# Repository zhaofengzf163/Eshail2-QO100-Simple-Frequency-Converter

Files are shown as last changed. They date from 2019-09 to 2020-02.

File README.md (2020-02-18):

# Eshail2-QO100-Simple-Frequency-Converter
   Eshail2 QO100 简易频率转换器

## 背景资料：
BG0AUB 中国HAM，QTH:NN33   .从2019年2月开始对QO100同步卫星转发器产生兴趣，经过一些准备，在2月24日在QO100与PA3FYM完成了第一个QSO.当时使用的设备为limesdr mini+移动通讯基站改装的2.4G功放。经过半年的摸索,尝试设计制作了这个工作在QO100的上行频率转换器（集成LNB基准产生，自动检测PTT控制。只需一根馈线连接到频率变换器即可工作）实现一根馈线直连电台输出直连馈源LNB即可工作。
最初的思路来源于PE1CKK的一张框图
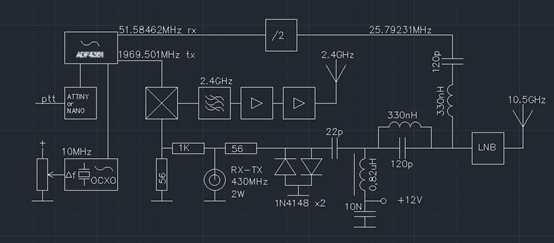
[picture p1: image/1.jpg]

整体思路很简洁。ADF4351在接收状态产生51.58462Mhz信号经过2分频后得到25.79231Mhz基准信号通过双工器送到LNB内部的PLL基准输入。（例如：没有经过修改的LNB本振为9750Mhz，QO100 cw信标10489.550，如果没有任何改动那么IF=10489.550-9750=739.550，为了把IF调整到430Mhz，方便电台直接接收，需要把LNB本振调整到10489.550-430.550=10050Mhz。LNB内部使用25M晶振作为PLL基准，调整这个基准频率就可以调整PLL输出。于是就有了25.7923）这样LNB会输出稳定的430M中频信号，方便全模式电台直接接收。
    发射部分：ADF4351在发射状态产生1969.500Mhz。电台发射信号430.550Mhz，经过混频器上变频后得到1969.5+430.550=2400.05Mhz。经过滤波放大后送到馈源发射上行到卫星。

## 技术方案：
1：频率转换器:  adf4351为核心的PLL。通过ATTINY13控制，产生的RX本振经过SPF5189放到后送入74ac74二分频，经过滤波后送入LNB.当检测到PTT时，产生的TX本振经过SPF5189放大后（10DB）送入HMC213混频器，同时电台送入的430M信号经过衰减器后(13DB)送入混频器，得到2.4G的输出到SF2124滤波后经过一级SPF5189放大后，再次经过SF2124滤波后输出。最终获得约4-5db的纯净输出。(PCB集成了ATTINY13，作为RX/TX收发频率转换控制，PTT信号通过检测430Mhz信号自动获取方便使用)
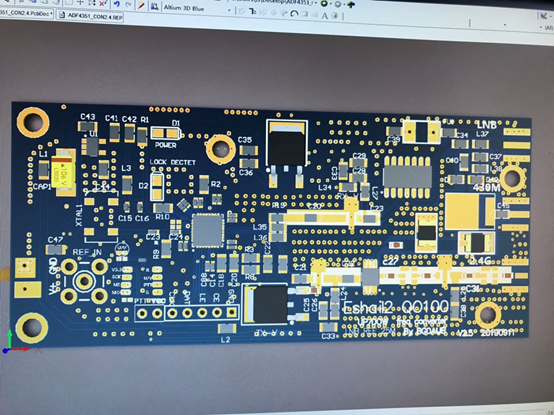
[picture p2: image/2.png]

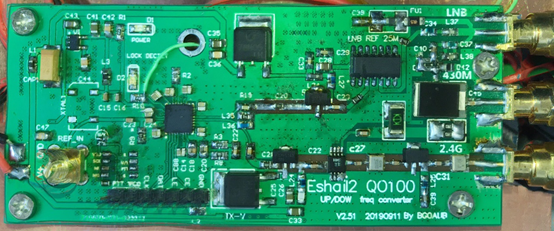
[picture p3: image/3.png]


2: S波段前置放大器（-5DB输入30DB输出）三级组成。输入信号经过滤波器后进入E5放大后再次滤波然后经过AH1驱动FLL357最终输出30-32DB.P1DB=30   PCB使用的廉价的FR4 0.8mm板材。
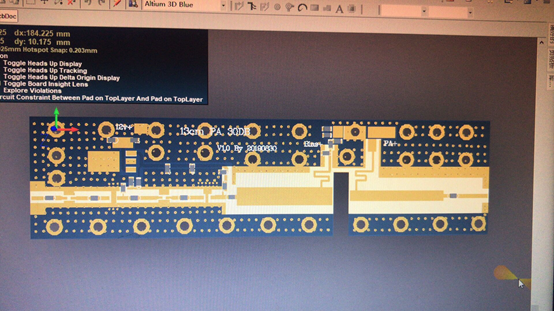
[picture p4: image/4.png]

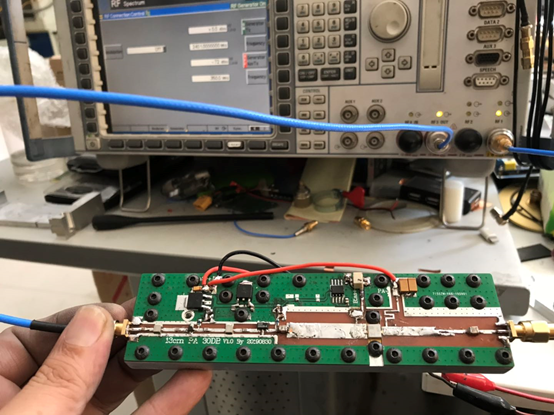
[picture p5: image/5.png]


3：S波段末级放大器 （40+DB输出）。MRF21045,仍然时廉价的FR4 0.8mm板材，实际测试在30db输入时可以得到40-42db输出。P1DB=39
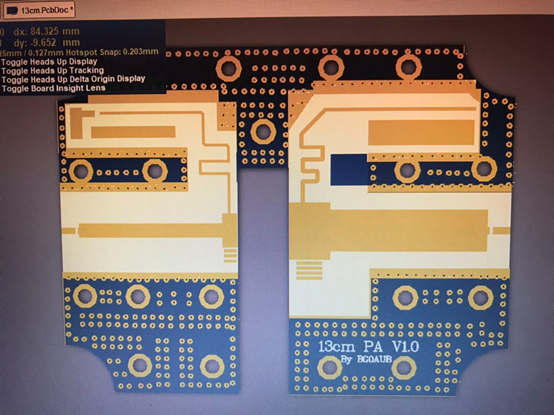
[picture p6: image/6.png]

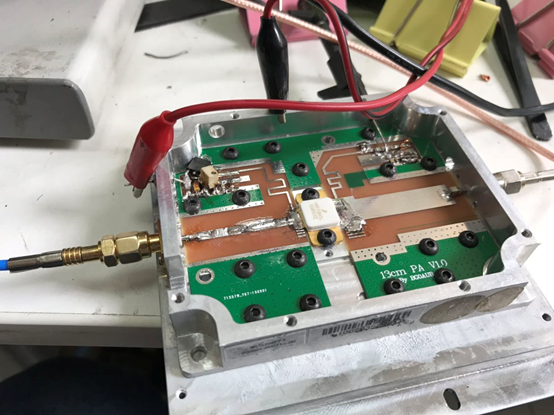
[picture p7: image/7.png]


在一个月时间里设计安装调试了三块PCB。基本都达到了设计要求。可以很好的实现QO100的上行工作和LNB基准输出。

## 目前的问题：
1：由于电路比较简单,没有绘制SCH电路图直接绘制了PCB。所以PCB文件的标号和网络比较混乱，但是实际没有错误。ADF4351部分有电路图参考。
2：由于对频率转换部分的功耗估计不足，稳压IC工作温度比较好，需要7V输入，并良好散热，最好在pcb底部使用铜片焊接散热器
3：adf4351频率基准没有使用GPSDO,使用了可以微调的OCXO,便于微调频率误差。

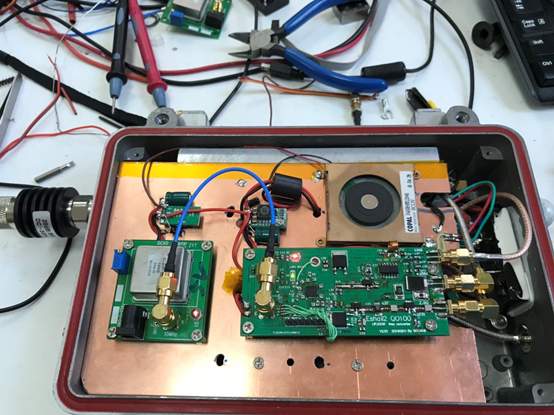
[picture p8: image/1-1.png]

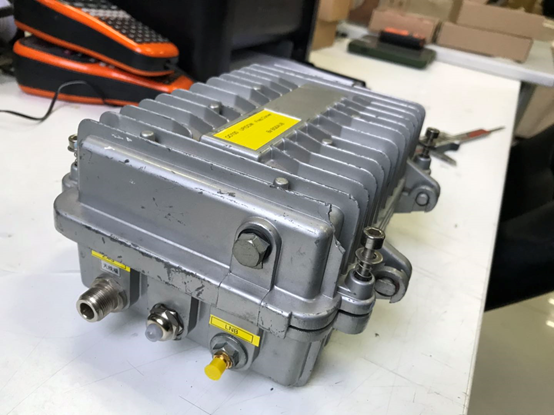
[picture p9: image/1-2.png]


目前的设计还是一个原始验证型，只是经过很短时间的测试。可能有一些未知的错误。仅供参考
在此感谢曾经热心帮助过我的朋友们,这是HAM精神的具体体现。。。

                            BG0AUB
                           20190922

20190925
重新组装了一套3块PCB。调试后性能一致。主要时为了验证可重复性。ADF4351转换器PCB换装了e5+ah1测试，25M基准输出幅度变大了达到13db。TX变化不大。
调试的难点在于FLL357与MRF21045的微带阻抗匹配，需要一点经验和技巧，特别时21045 ，装好所有器件上电几乎没有增益或者负增益，通过调整微带阻抗匹配，从-2DB调整到+11DB.这个有空了我写一个调试说明。
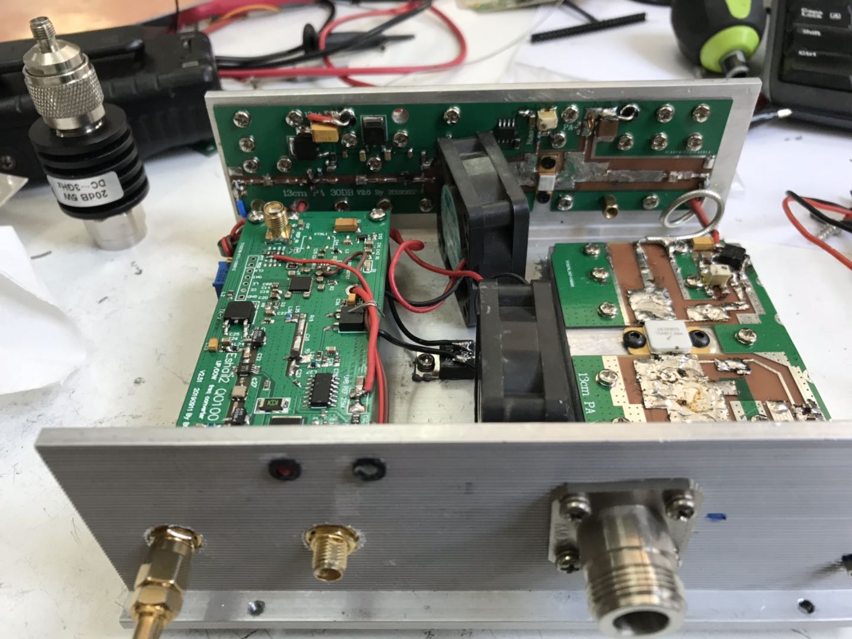
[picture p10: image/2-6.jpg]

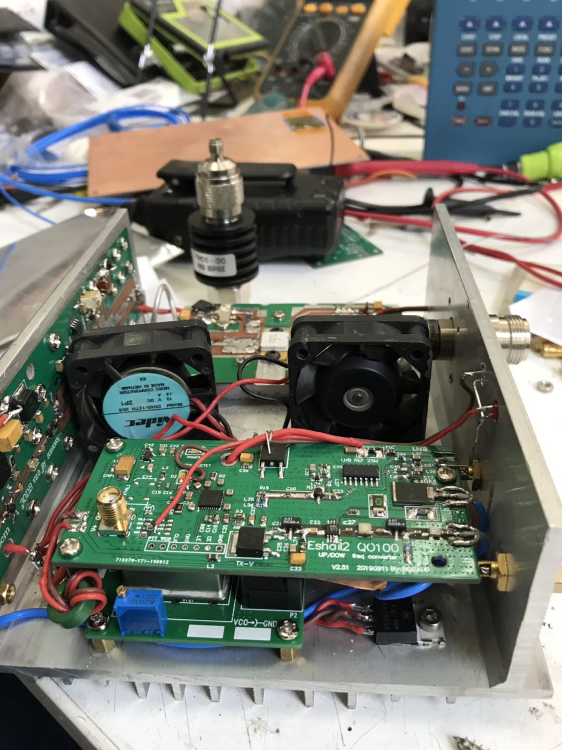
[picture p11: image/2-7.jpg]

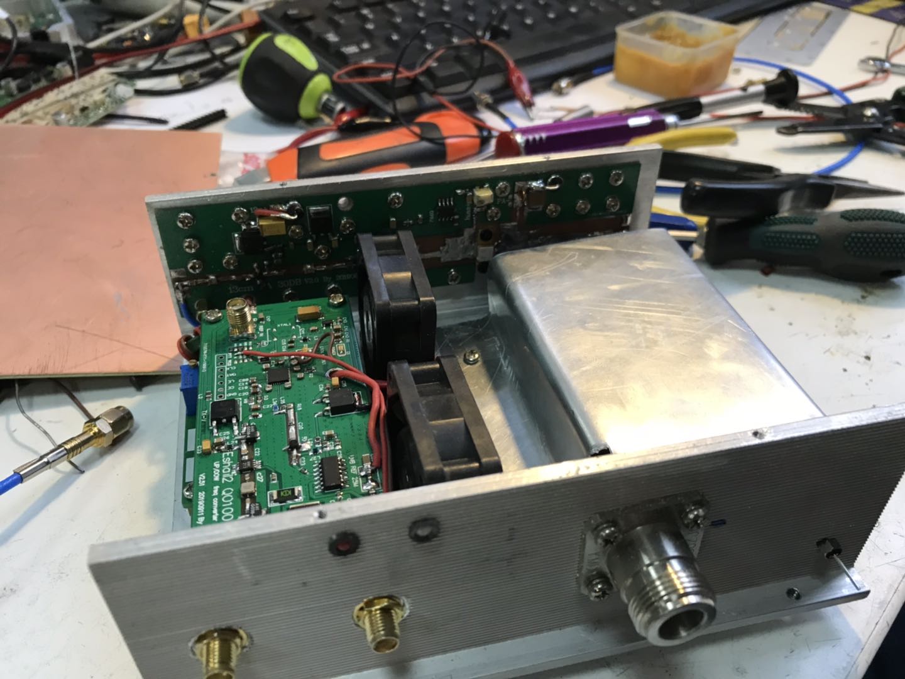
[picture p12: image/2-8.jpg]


20190929
根据昨晚测试情况，RX回路衰减器重新调整为20db。LNB基准增加了10db衰减器。LNB基准幅度目前为-5DB。

20190930
测试了74ac74分频电路，测试发现工作不稳定，需要保持VPP 2.0v以上输入才能可靠工作。20191014
最近工作测试整个系统工作良好。再次组装了一块变频板。调整了mmic型号。adf4351输出设置+2db。up上行lo第一级放大使用spf5189，输出10-11db到hmc213.混频后放大器使用SBB5089.经过滤波后2.4g输出在10-13db。
LNB基准adf4351设置-4db。使用SBA5089效果很好
同时整机功耗可以降低一些。发热量减少很多

20200109
测试了使用MRF21085的版本。输出功率>46dbm，前置放大器使用SBB5089+AH1+FLL357.更换了插损更小的LFB212G45SG8A127村田滤波器，前级增益达到了38db 后级增益13db
目前所有的微带匹配已经经过优化，只需要少量的调试即可达到设计指标。

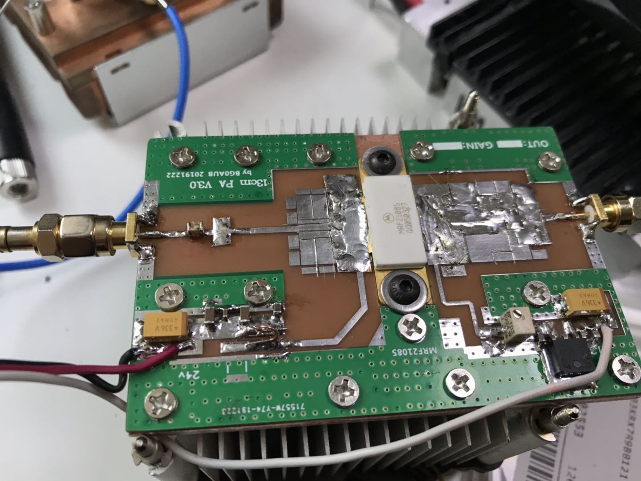
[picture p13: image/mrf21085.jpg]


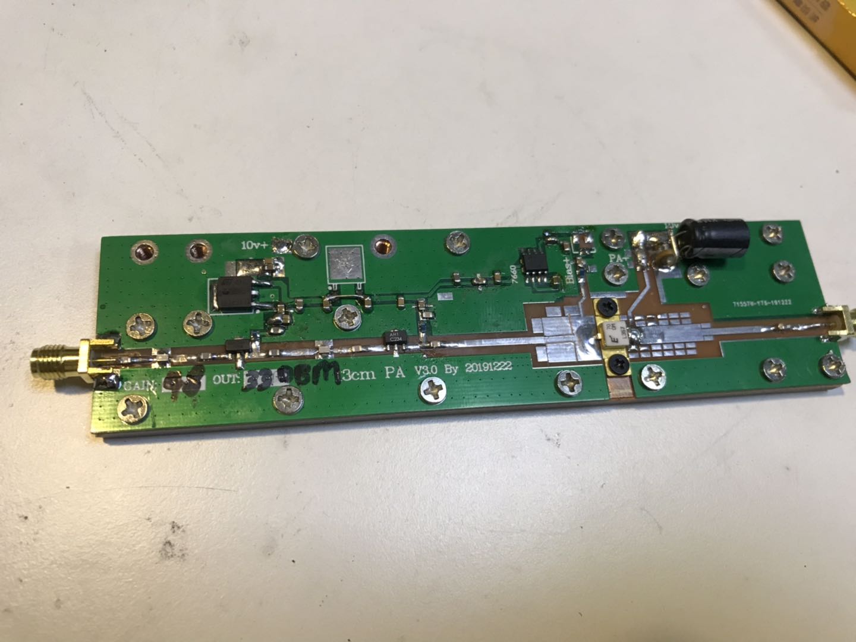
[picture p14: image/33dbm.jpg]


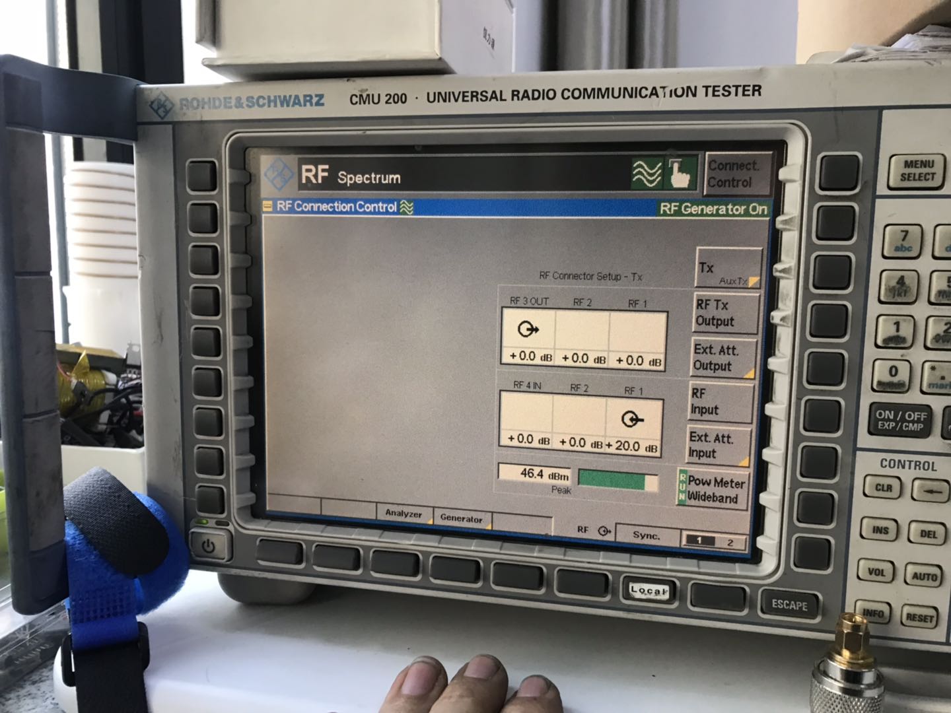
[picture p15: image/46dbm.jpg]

待续。。。。。

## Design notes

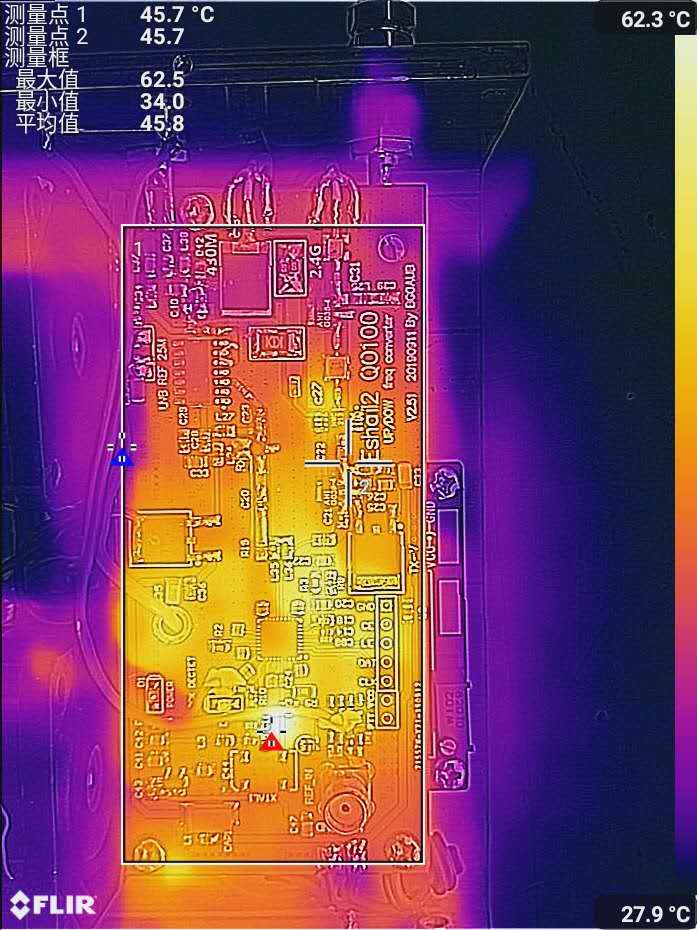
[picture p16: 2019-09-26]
image/flri-2.jpg

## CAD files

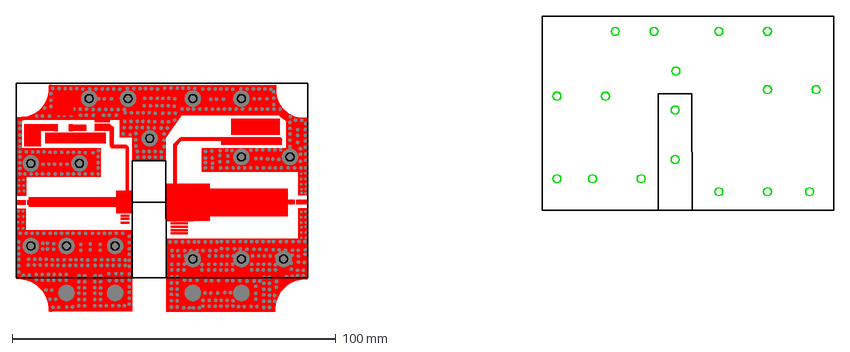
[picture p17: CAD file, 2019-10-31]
10w散热机加工.dxf
252.5 x 91.3 mm

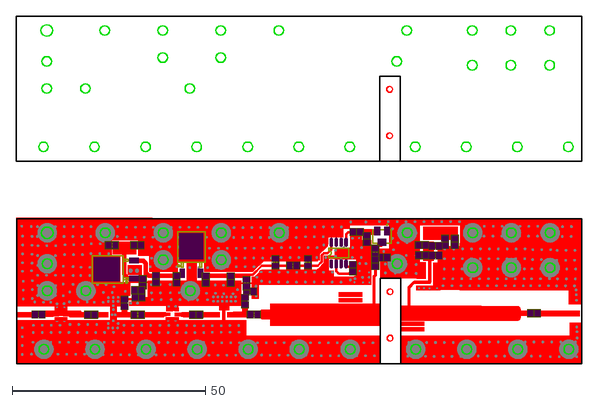
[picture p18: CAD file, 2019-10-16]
1w散热机加工.dxf
146.3 x 89.9

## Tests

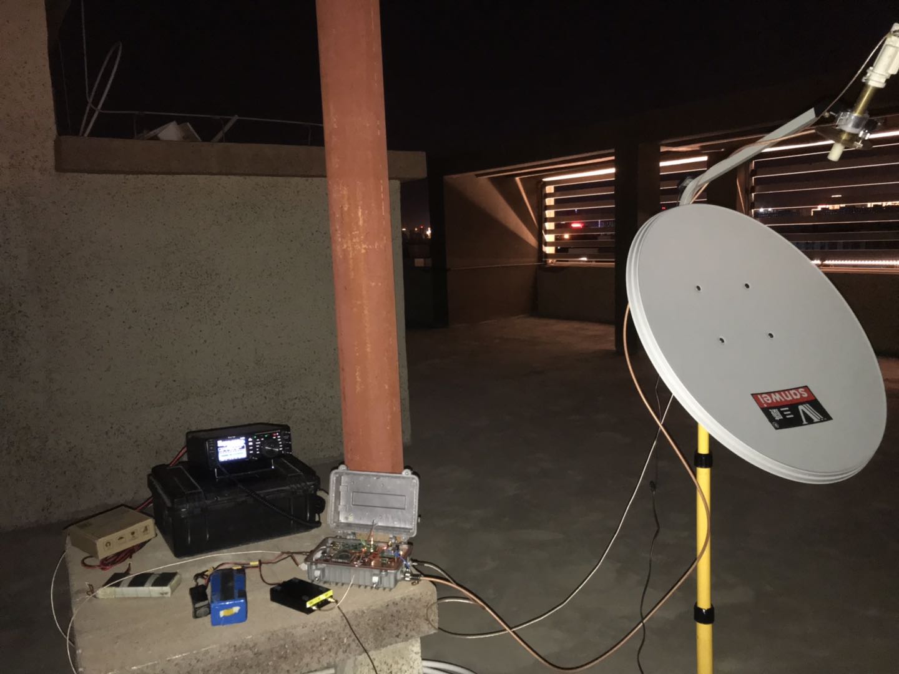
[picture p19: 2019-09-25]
image/TEST.jpg

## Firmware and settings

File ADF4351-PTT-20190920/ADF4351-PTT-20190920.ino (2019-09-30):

/* Very simple software for PLL ADF4351 and ATTiny13
  can be compiled with arduino and microcore
  https://github.com/MCUdude/MicroCore
  v 0.1 Ondra OK1CDJ 9/2018 ondra@ok1cdj.com

  Please check the ADF4351 datasheet or use ADF4351 software
  to get PLL register values.

  PIN layout
  PB4 ADF4531 clock (CLK)
  PB3 ADF4531 data (DATA)
  PB2 ADF4531 latch enable (LE)

*/
/****************************** 25M基准****************************************************8
  // TX  Fout= 1960.5 MHz +5dBm LO= 1690.5 MHz +439.55 MHz=2400.05MHZ
  r0 = 0X4E00A8;
  r1 = 0X80080C9;
  r2 = 0X4E42;
  r3 = 0X4B3;
  r4 = 0X9C803C;
  r5 = 0X580005;
  //RX Fout= 300 MHz +5dBm LO= 300MHz -739.55 MHz=439.55MHZ
  r0 = 0X300000;
  r1 = 0X8008011;
  r2 = 0X4E42;
  r3 = 0X4B3;
  r4 = 0XBC803C;
  r5 = 0X580005;

************************************** 10M 基准*****************************************************************
  // TX  Fout= 1960.5 MHz +5dBm LO= 1690.5 MHz +439.55 MHz=2400.05MHZ
  r0 = 0XC40008;
  r1 = 0X8008051;
  r2 = 0X4E42;
  r3 = 0X4B3;
  r4 = 0X95003C;
  r5 = 0X580005;
  //RX Fout= 300 MHz +5dBm LO= 300MHz -739.55 MHz=439.55MHZ
  r0 = 0x780000;
  r1 = 0X8008011;
  r2 = 0X4E42;
  r3 = 0X4B3;
  r4 = 0XB5003C;
  r5 = 0X580005;

  20190330 修改了外部基准由gpsdo输入。10M  增加了PTT输入 RX/TX切换输出   by BG0AUB

  20190920 修改了ADF4351控制数据，rx=51.584625 tx=1969.501 增加了PTT延时。rx/tx切换指示 by BG0AUB
*////////////////////////////////////////////////////////////////////////////////////////////////////
// PLL registers
//long int r0, r1, r2, r3, r4, r5;
//long int TX_R[6] = {0X4E00A8, 0X80080C9, 0X4E42, 0X4B3, 0X9C803C, 0X580005};
//long int RX_R[6] = {0X300000, 0X8008011, 0X4E42, 0X4B3, 0XBC803C, 0X580005};

int LE = 2;                                 //EL引脚
int CLK = 4;                                 //CLK引脚
int DAT = 3;                                //DAT引脚
int RX_TX = 0;                              //PTT
int LED = 1;                                //RX/TX_LED
int RX_P;
int TX_P;


void write2PLL(uint32_t PLLword)
{ // clocks 32 bits word  directly to the ADF4351
  // msb (b31) first, lsb (b0) last
  for (byte i = 32; i > 0; i--)
  { // PLL word 32 bits
    (PLLword & 0x80000000 ? PORTB |= 0b00001000 : PORTB &= 0b11110111);  // data on PB3
    PORTB |= 0b00010000;                   // clock in bit on rising edge of CLK (PB4 = 1)
    PORTB &= 0b11101111;                   // CLK (PB4 = 0)
    PLLword <<= 1;                         // rotate left for next bit
  }
  PORTB |= 0b00000100;                   // latch in PLL word on rising edge of LE (PB2 = 1)
  PORTB &= 0b11111011;  // LE (PB2 = 0)
  delayMicroseconds(1);
}

void setup ()
{
  //DDRB  = 0xff; // PB are all outputs
  //PORTB = 0x00; // make PB low
  pinMode(LE, OUTPUT);
  pinMode(CLK, OUTPUT);
  pinMode(DAT, OUTPUT);
  pinMode(LED, OUTPUT);
  pinMode(RX_TX, INPUT);
  digitalWrite(LED, 1);
  delay(500);


  //  //10M基准 1969.501M
  write2PLL(0XBC803C & 0xffffffdf);  //关闭输出
  write2PLL(0X580005);
  // write2PLL(0XE5002C); //+2DB
  write2PLL(0XE500FC);   //+5DB
  write2PLL( 0X4B3);
  write2PLL(0X4E42);
  write2PLL(0X800A711);
  write2PLL(0XA50588);
  digitalWrite(LED, 0);
}

// main loop
void loop()
{ if (digitalRead(RX_TX) == 1)
  { if (RX_P == 0)
    { delay(700);
      //10M基准       51.584625 LNB REF
      write2PLL(0XBC803C & 0xffffffdf);  //关闭输出
      write2PLL(0X580005);
      // write2PLL(0XE5002C); //+2DB
      write2PLL(0XE500FC);   //+5DB
      write2PLL( 0X4B3);
      write2PLL(0X4E42);
      write2PLL(0X800A711);
      write2PLL(0XA50588);
      RX_P = 1;
      TX_P = 0;
      digitalWrite(LED, 0);
    }
  }
  else
  { if (TX_P == 0)
    {
      //10M基准 1969.501M
      write2PLL(0XBC803C & 0xffffffdf);  //关闭输出
      write2PLL(0X580005);
      write2PLL(0X928034);
      write2PLL(0X4B3);
      write2PLL(0X8E42);
      write2PLL(0X800CE21);
      write2PLL(0X189BE88);
      TX_P = 1;
      RX_P = 0;
      digitalWrite(LED, 1);
    }
  }

}
//*****************************THE END*********************************************************************8
// delay(10);
//TX ON/OFF can be used for CW keying
//write2PLL(r4 & 0xffffffdf);

////void write_dat(long int *r)
//// write from r5 to r0
//{ write2PLL(r5);
//  write2PLL(r4);
//  write2PLL(r3);
//  write2PLL(r2);
//  write2PLL(r1);
//  write2PLL(r0);
//}

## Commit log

2019-09-23 Create ADF4351-PTT-20190920.ino.hex
    编译T13 hex
2019-09-25 制作了第二套进行验证，微调PCB。上传了新图片
    [13cmPA_MRF21045-FR4-0.8_V1.2.PcbDoc]
2019-09-26 器件运行温度测量
2019-09-30 调整了rx-lo输出电平
2019-09-30 修复了一些无关紧要的BUG
    [13CMPA_E5-AH1-FLL357-FR4-0.8_V2.0.PcbDoc, 13CMPA_E5-AH1-FLL357-FR4-0.8_V2.01.PcbDoc]
2019-10-09 调整了TX_ATT数值
2019-10-16 散热沉铜加工图纸
    [10w散热机加工.dxf, 13CMPA_E5-AH1-FLL357-FR4-0.8_V2.01.PcbDoc, 1w散热机加工.dxf]
2019-10-31 Update 10w散热机加工.dxf
    fix bug
    [10w散热机加工.dxf]
2020-01-09 更新说明文档
2020-01-09 更换村田滤波器版本
2020-02-18 修改了ptt接入电。提高ptt启动灵敏度
